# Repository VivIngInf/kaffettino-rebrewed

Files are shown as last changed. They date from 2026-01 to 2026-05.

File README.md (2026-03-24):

# ☕ Kaffettino Rebrewed (v2.0)

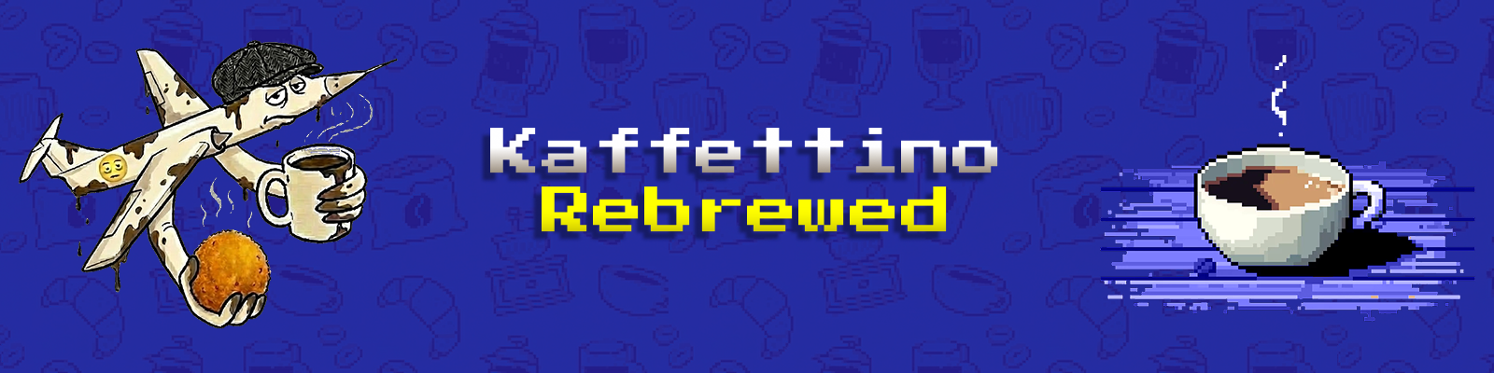
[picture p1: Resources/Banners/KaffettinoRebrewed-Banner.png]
Project's banner


> Sistema embedded NFC per la gestione automatizzata delle consumazioni, progettato per ambienti reali e scalabilità.




## ☀️ "Buongiornissimo... Arrikaffè!?!?!"

Kaffettino Rebrewed è la **nuova generazione del [progetto Kaffettino](https://github.com/VivIngInf/VivereKaffettino)**: non un semplice aggiornamento, ma una **riscrittura completa** pensata per essere più efficiente, robusta e pronta al futuro.

Se la prima versione era un prototipo brillante, questa è la sua evoluzione:
**hardware custom**, software **modulare** e una filosofia più **industriale**.

## ☕ Cos'è Kaffettino?

Vivere Kaffettino è una **suite** che permette agli utenti dell’Università di Palermo, appartenenti a Vivere Ingegneria, di **segnare le proprie consumazioni** (non solo di caffè) in modo semplice e veloce.

Il sistema è basato su un **ESP32 con lettore NFC**:

- L’utente avvicina la propria card
- Viene verificato il saldo
- Il costo del caffè viene scalato automaticamente

La ricarica viene poi gestita da un amministratore.

## 🤔 Cos’è cambiato con Rebrewed?

Kaffettino Rebrewed nasce come una **reingegnerizzazione completa** del [progetto originale](https://github.com/VivIngInf/VivereKaffettino), mantenendo lo spirito ma **rivoluzionando l’architettura**.

🔧 **Hardware & firmware**:

- PCB custom progettata ad hoc tramite KiCAD
- Firmware completamente riscritto e modularizzato
- Espandibilità grazie a morsettiere per device I2C e SPI
- Pensato per essere replicabile e manutenibile
- Aggiornamenti OTA

🖥️ **Backend**:

- Riscritto tutto il backend in TypeScript
- Integrato con il resto della suite Vivere
- Aggiunto Sito Web allo stack
- Continuazione del bot Telegram già presente nella versione 1

📡 **Connettività intelligente**:

- Riconnessione automatica
- Captive portal per configurazione WiFi
- Antenna esterna per maggiore copertura

🧯 **Gestione errori**:

- Sistema strutturato di gestione errori
- Debug più semplice
- Distinzione tra errori (bloccanti) e warning

## 🧱 Architettura

Kaffettino Rebrewed è composto da:

- ESP32 → legge NFC e comunica con backend
- Backend → gestisce utenti, saldo e logiche
- Web App → interfaccia admin ed utente per statistiche e gestione
- Bot Telegram → interazioni rapide

Tutti i **componenti** comunicano tramite **API REST**.

## 📚 Documentazione

La **documentazione** (utente e amministrativa) è disponibile nella **cartella Docs**.

## 📁 Struttura REPO

> WIP! 🚧

## 🖼️ Image Gallery

> WIP! 🚧

## ♥️ Credits

Realizzato **con amore**, debug e decisamente **troppa caffeina** dai ragazzi di Vivere Ingegneria Dev Hub

<table>
  <tr>
      <th>Daniele Susino</th>
      <th>Antonio Murabito</th>      
  </tr>
  <tr>
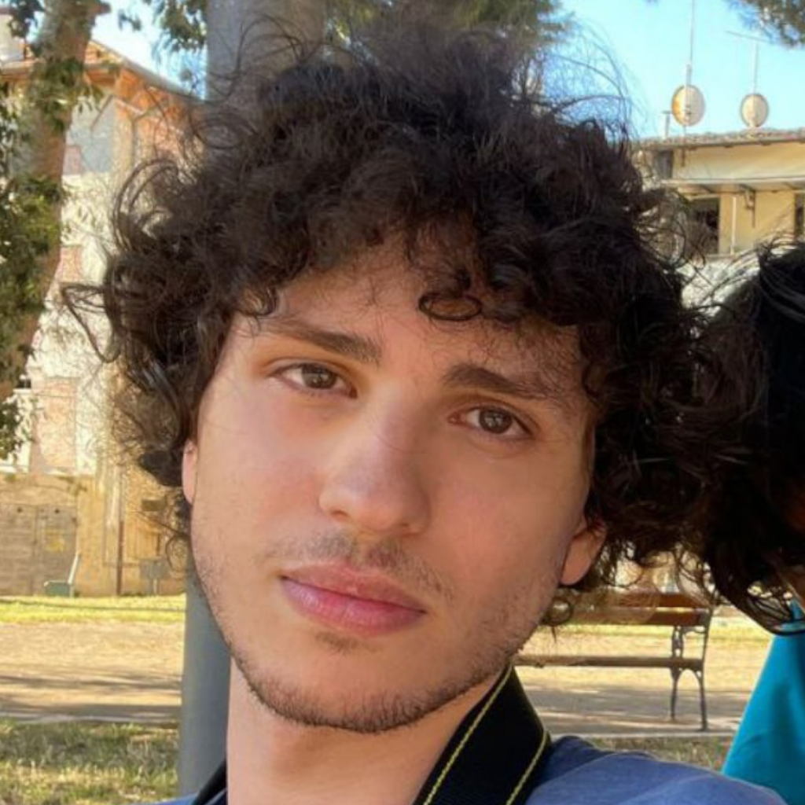
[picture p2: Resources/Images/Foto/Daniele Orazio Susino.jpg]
Daniele Orazio Susino
      <td></td>
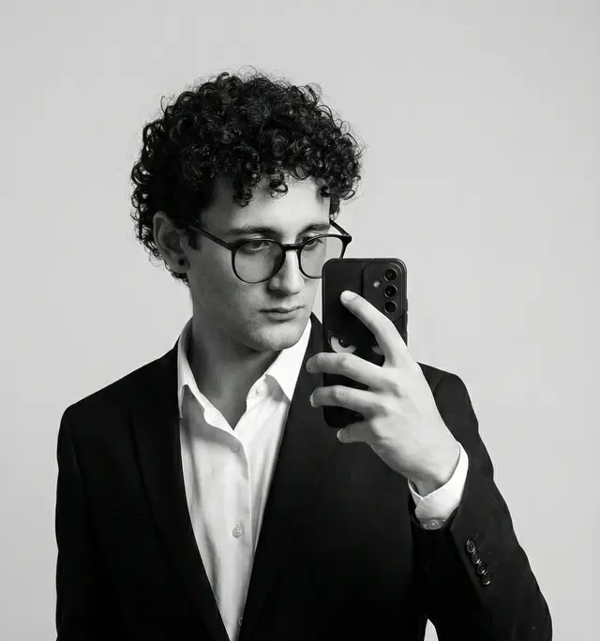
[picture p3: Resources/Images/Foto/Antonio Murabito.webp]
Antonio Murabito
      <td></td>
  </tr>
  <tr>
      <td>Embedded</td>
      <td>Full Stack</td>
  </tr>
  <tr>
      <td>
         <a href="https://www.instagram.com/_antonio.jar/">Instagram 📸</a><br>
         <a href="https://www.linkedin.com/in/susinodaniele/">LinkedIn 👔</a><br>         
         <a href="https://www.susino.dev">Sito 🌐</a>
      </td>
      <td>
         <a href="https://www.instagram.com/_antonio.jar/">Instagram 📸</a><br>
         <a href="https://www.linkedin.com/in/z3ros4n/">LinkedIn 👔</a><br>         
         <a href="https://www.msworks.it">Sito 🌐</a>
       </td>
  </tr>
</table>

---

Si ringrazia, per l'aiuto dato, Nicolas Bruno di [Objex Labs](https://objexlabs.com/)
<br>
Basato su: [Vivere Kaffettino](https://github.com/VivIngInf/VivereKaffettino)

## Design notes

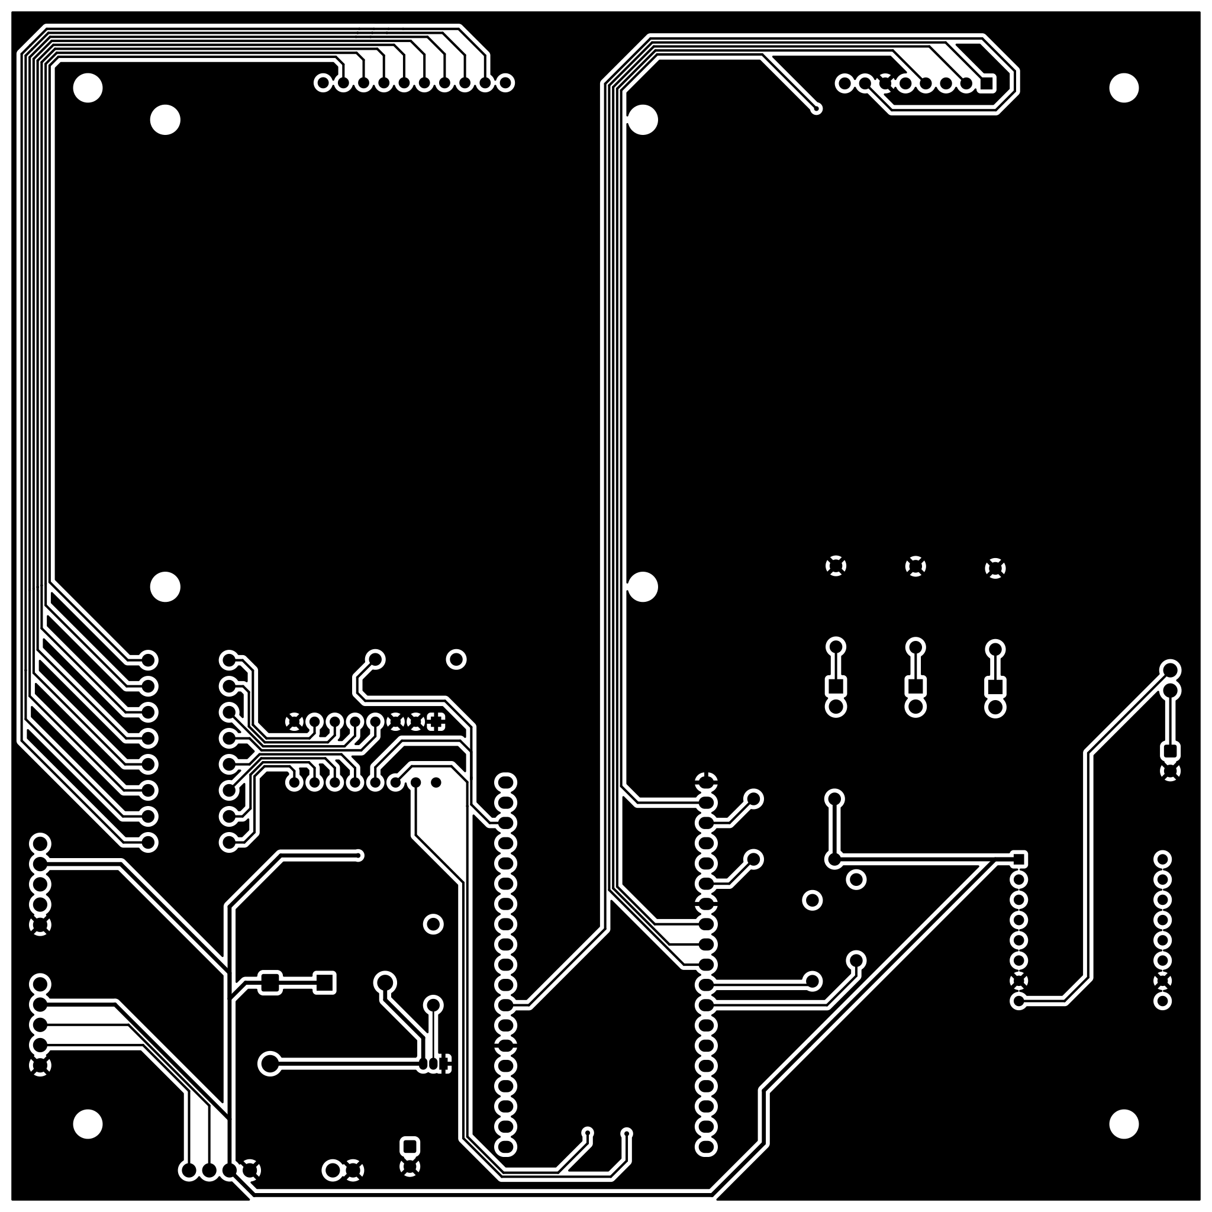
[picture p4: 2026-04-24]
Resources/Electronics/Kaffettino/Export/KaffettinoPCB/layers/PNGS/F_Cu.png

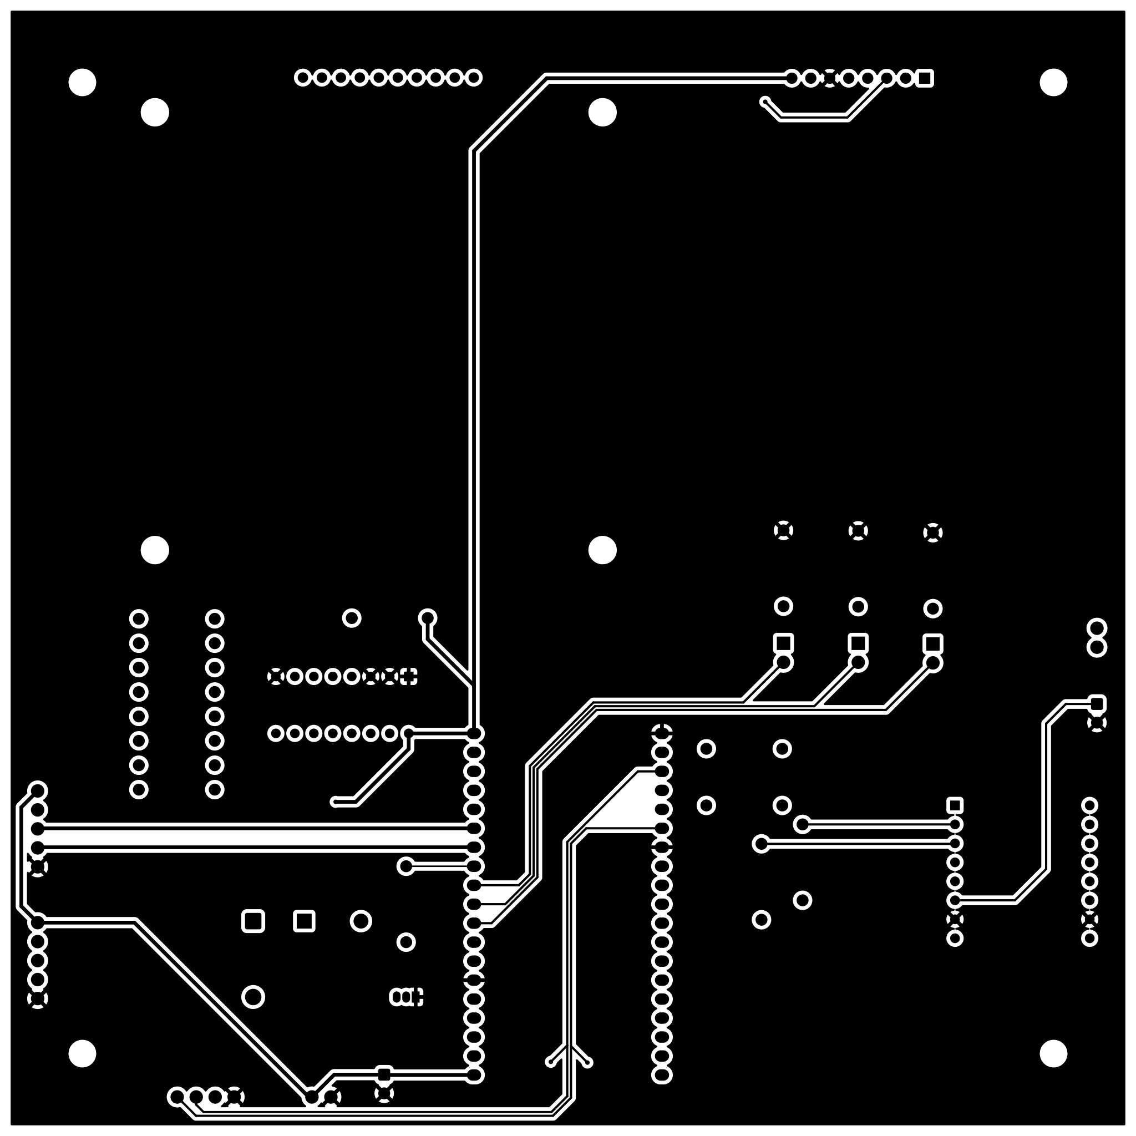
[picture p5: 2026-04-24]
Resources/Electronics/Kaffettino/Export/KaffettinoPCB/layers/PNGS/B_Cu.png

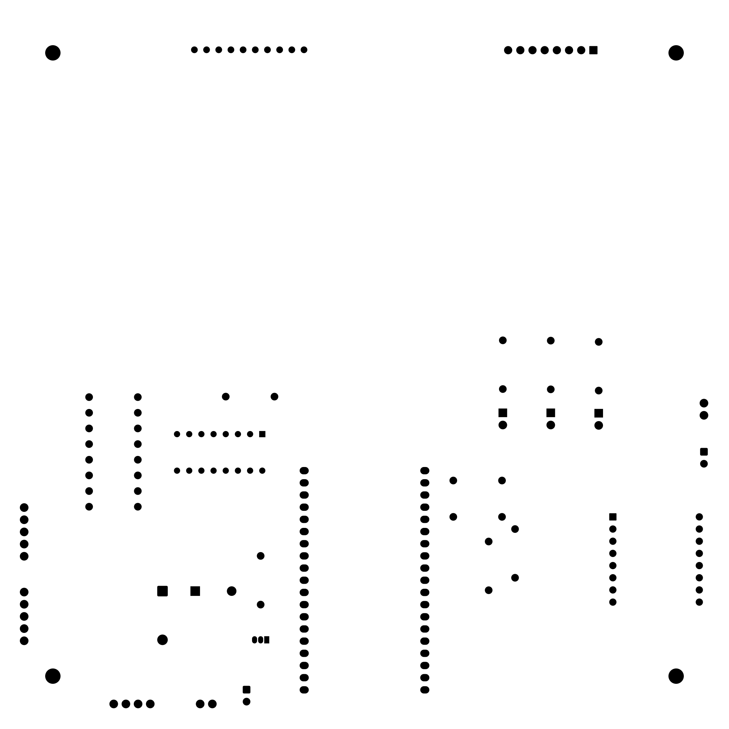
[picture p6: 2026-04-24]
Resources/Electronics/Kaffettino/Export/KaffettinoPCB/layers/PNGS/B_Mask.png

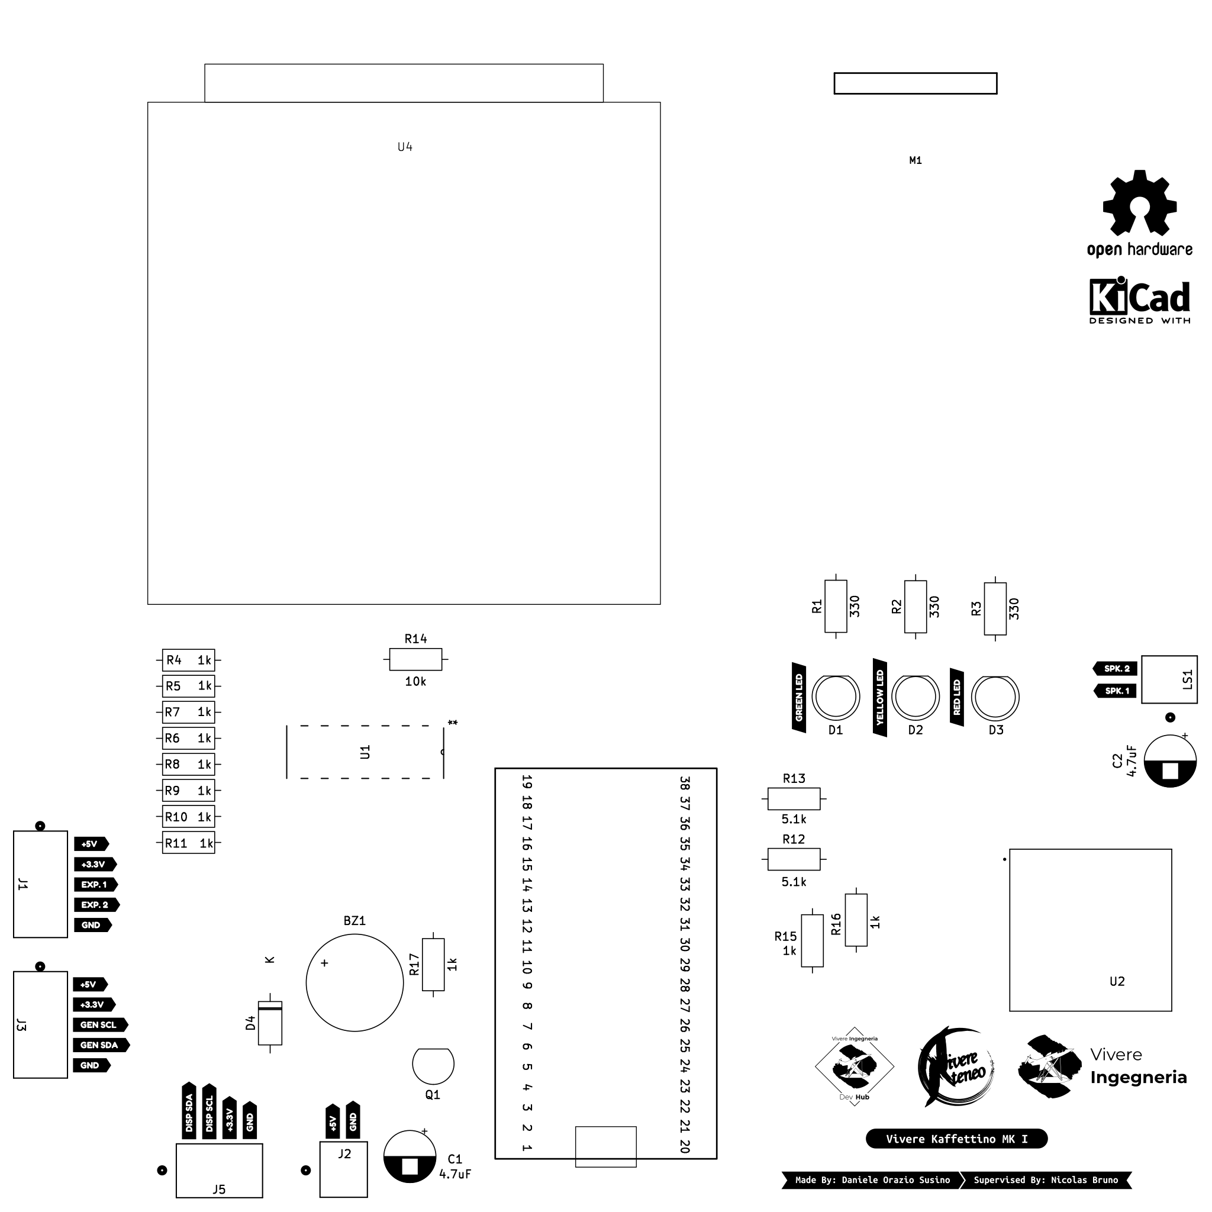
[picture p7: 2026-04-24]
Resources/Electronics/Kaffettino/Export/KaffettinoPCB/layers/PNGS/F_SilkS.png

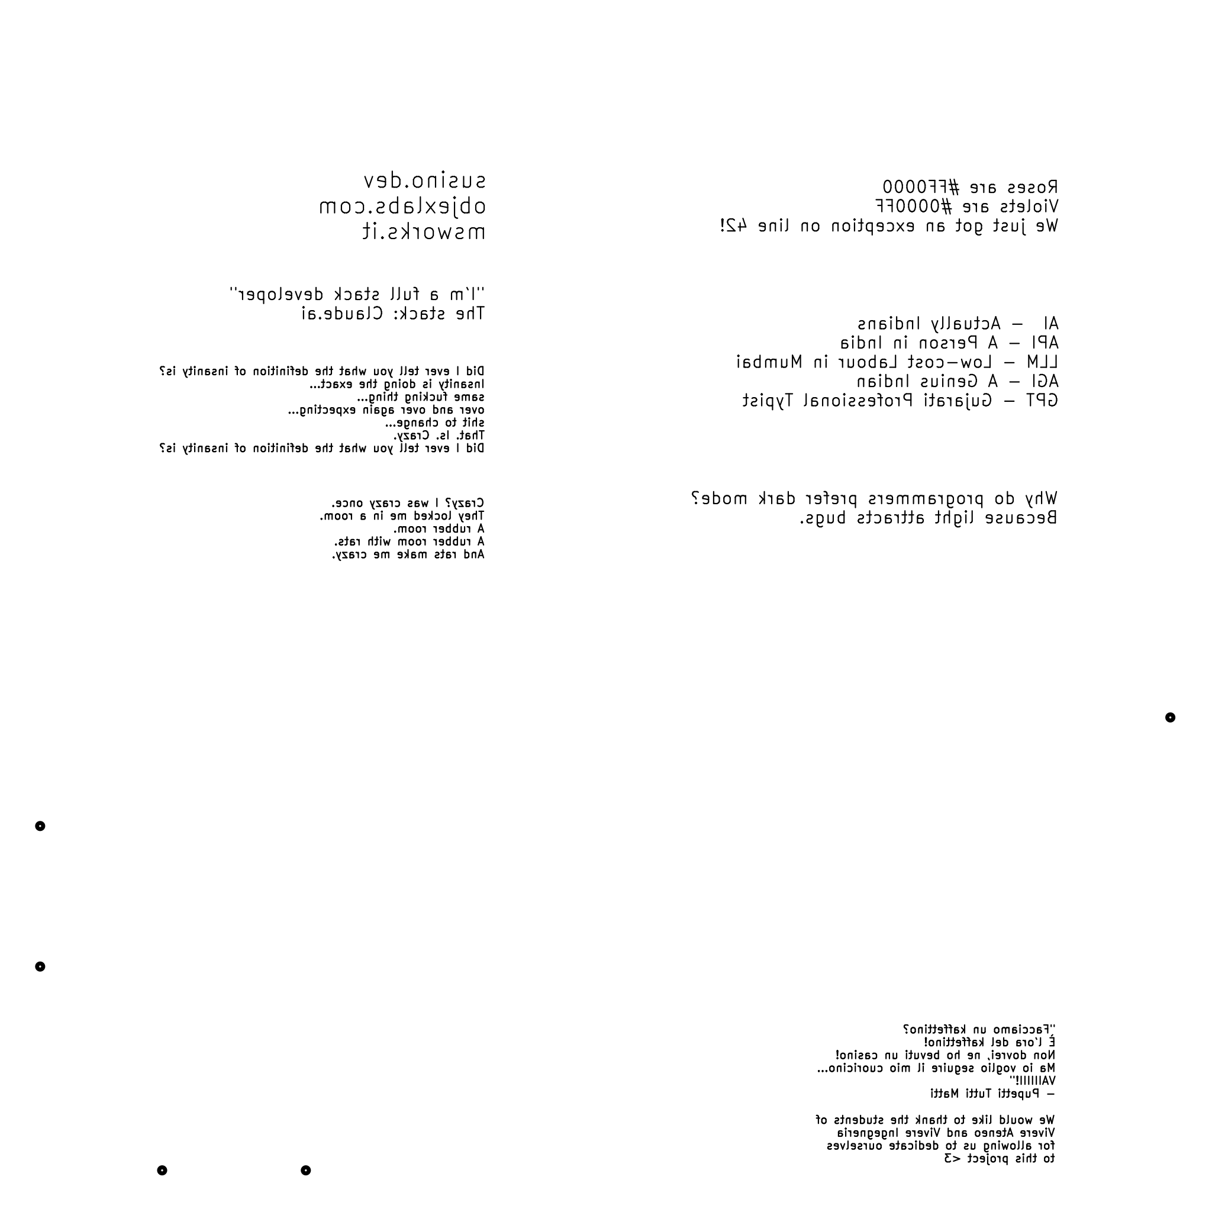
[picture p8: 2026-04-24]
Resources/Electronics/Kaffettino/Export/KaffettinoPCB/layers/PNGS/B_SilkS.png

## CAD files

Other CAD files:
Resources/3D Models/Keypad/Keypad.FCStd
Resources/Electronics/Kaffettino/Export/PCB.blend
Resources/Electronics/Kaffettino/Export/PCB_Ugly.blend

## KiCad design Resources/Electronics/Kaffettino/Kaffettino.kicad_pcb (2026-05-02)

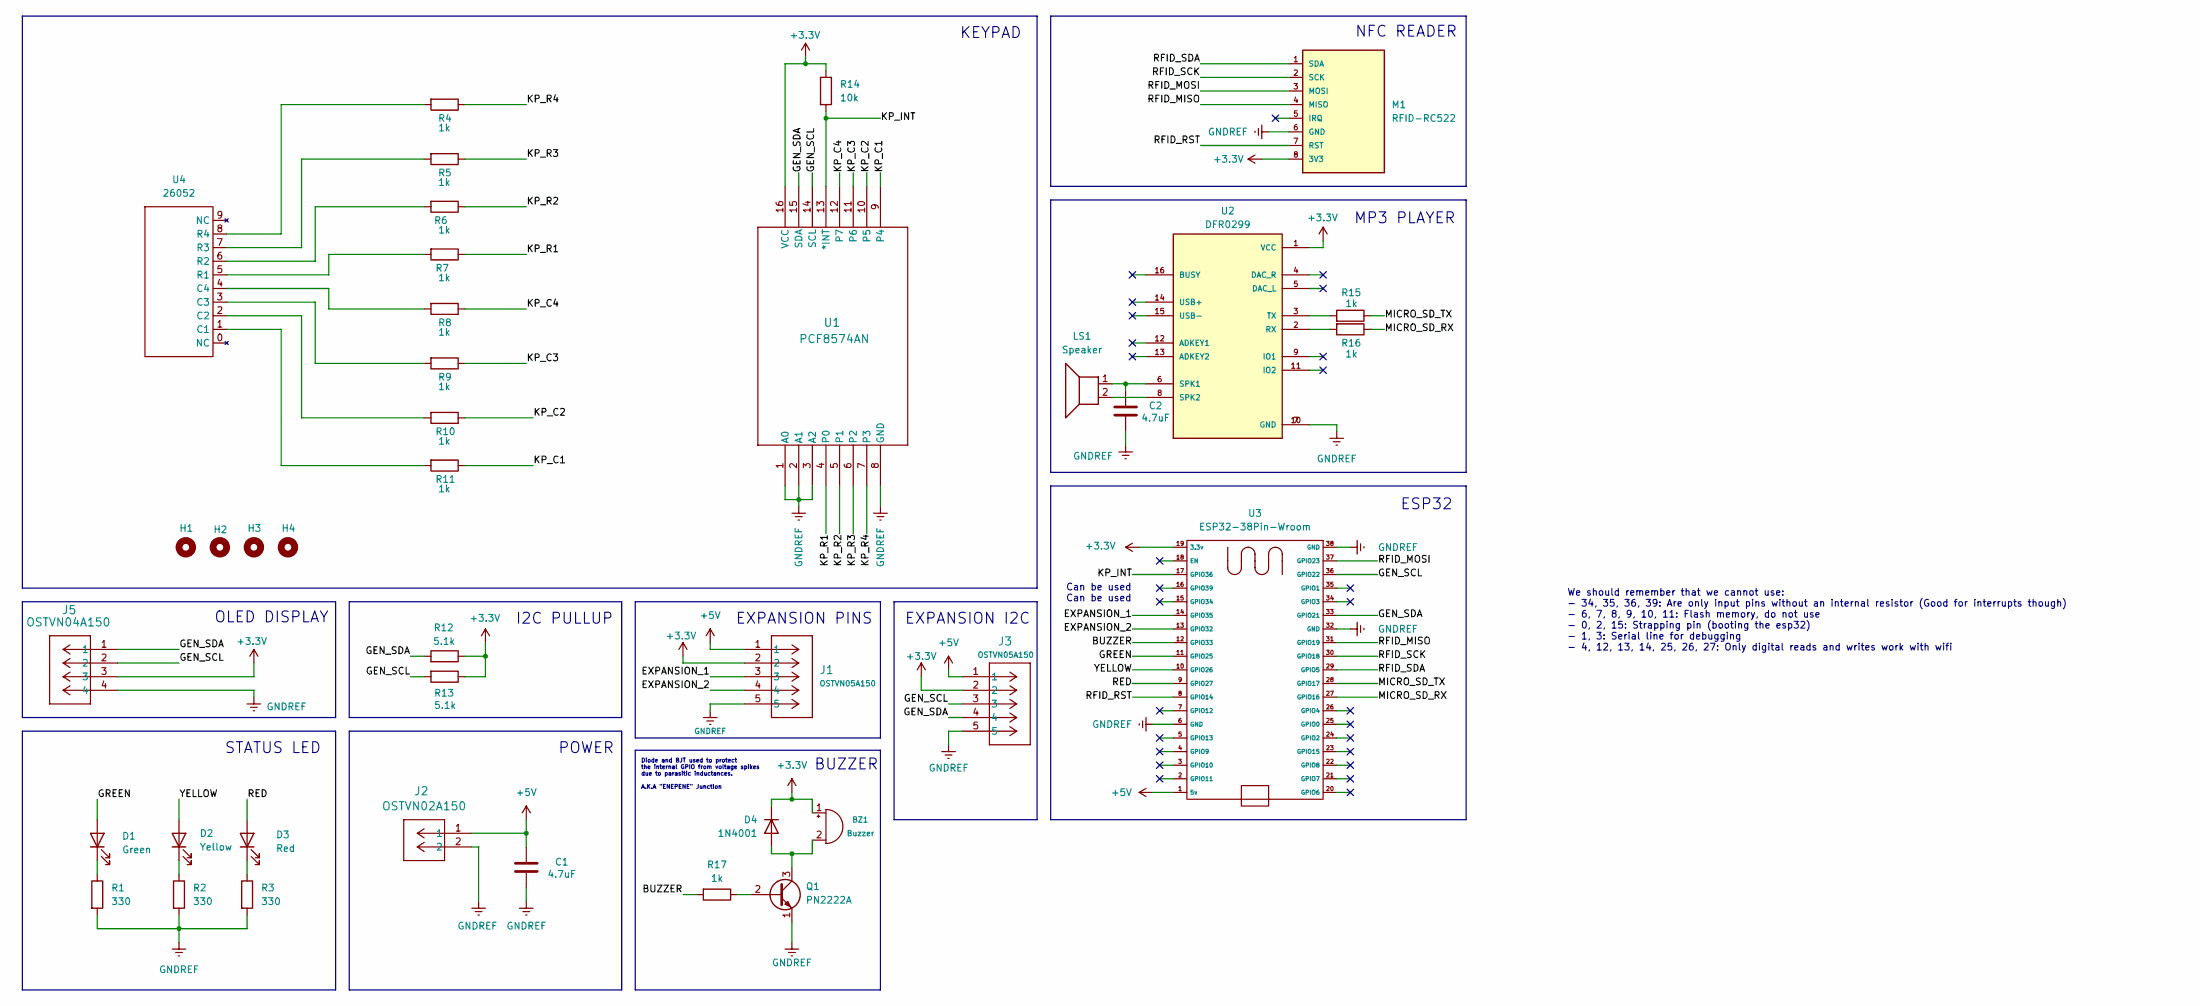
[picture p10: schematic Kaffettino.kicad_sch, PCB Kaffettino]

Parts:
BZ1: Buzzer; Buzzer_12x9.5RM7.6
C1, C2: 4.7uF; CP_Radial_D6.3mm_P2.50mm
D1: Green; LED_D5.0mm
D2: Yellow; LED_D5.0mm
D3: Red; LED_D5.0mm
D4: 1N4001; D_DO-41_SOD81_P10.16mm_Horizontal
H1, H2, H3, H4: MountingHole; MountingHole_3.2mm_M3
J1, J3: OSTVN05A150; CONN5_516x256_OST
J2: OSTVN02A150; CONN_OSTVN02A150_OST
J5: OSTVN04A150; CONN_OSTVN04A150_OST
LS1: Speaker; CONN_OSTVN02A150_OST
M1: RFID-RC522; MPN RFID-RC522
Q1: PN2222A; TO-92_Inline
R1, R2, R3: 330; R_Axial_DIN0207_L6.3mm_D2.5mm_P10.16mm_Horizontal
R4, R5, R6, R7, R8, R9, R10, R11, R15, R16, R17: 1k; R_Axial_DIN0207_L6.3mm_D2.5mm_P10.16mm_Horizontal
R12, R13: 5.1k; R_Axial_DIN0207_L6.3mm_D2.5mm_P10.16mm_Horizontal
R14: 10k; R_Axial_DIN0207_L6.3mm_D2.5mm_P10.16mm_Horizontal
U1: PCF8574AN; N16
U2: DFR0299; MODULE_DFR0299
U3: ESP32-38Pin-Wroom; ESP32_38pin
U4: 26052; 26052 matrix keypad 4x4

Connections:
+3.3V: BZ1.1 (+), D4.1 (K), J1.2, J3.2, J5.3, M1.8 (3V3), R12.1, R13.1, R14.1, U1.16 (VCC), U2.1 (VCC), U3.19 (3.3v)
+5V: C1.1, J1.1, J2.1, J3.1, U3.1 (5v)
/BUZZER: R17.2, U3.12 (GPIO33)
/EXPANSION_1: J1.3, U3.14 (GPIO35)
/EXPANSION_2: J1.4, U3.13 (GPIO32)
/GEN_SCL: J3.3, J5.2, R13.2, U1.14 (SCL), U3.36 (GPIO22)
/GEN_SDA: J3.4, J5.1, R12.2, U1.15 (SDA), U3.33 (GPIO21)
/GREEN: D1.2 (A), U3.11 (GPIO25)
/KP_C1: R11.1, U1.9 (P4)
/KP_C2: R10.1, U1.10 (P5)
/KP_C3: R9.1, U1.11 (P6)
/KP_C4: R8.1, U1.12 (P7)
/KP_INT: R14.2, U1.13 (*INT), U3.17 (GPIO36)
/KP_R1: R7.1, U1.4 (P0)
/KP_R2: R6.1, U1.5 (P1)
/KP_R3: R5.1, U1.6 (P2)
/KP_R4: R4.1, U1.7 (P3)
/MICRO_SD_RX: R16.1, U3.27 (GPIO16)
/MICRO_SD_TX: R15.1, U3.28 (GPIO17)
/RED: D3.2 (A), U3.9 (GPIO27)
/RFID_MISO: M1.4 (MISO), U3.31 (GPIO19)
/RFID_MOSI: M1.3 (MOSI), U3.37 (GPIO23)
/RFID_RST: M1.7 (RST), U3.8 (GPIO14)
/RFID_SCK: M1.2 (SCK), U3.30 (GPIO18)
/RFID_SDA: M1.1 (SDA), U3.29 (GPIO5)
/YELLOW: D2.2 (A), U3.10 (GPIO26)
GNDREF: C1.2, C2.2, J1.5, J2.2, J3.5, J5.4, M1.6 (GND), Q1.1 (E), R1.2, R2.2, R3.2, U1.1 (A0), U1.2 (A1), U1.3 (A2), U1.8 (GND), U2.7 (GND), U2.10 (GND), U3.6 (GND), U3.32 (GND), U3.38 (GND)
unnamed: BZ1.2 (-), D4.2 (A), Q1.3 (C)
unnamed: D1.1 (K), R1.1
unnamed: D2.1 (K), R2.1
unnamed: D3.1 (K), R3.1
unnamed: Q1.2 (B), R17.1
unnamed: R16.2, U2.2 (RX)
unnamed: C2.1, LS1.1, U2.6 (SPK1)
unnamed: LS1.2, U2.8 (SPK2)
unnamed: R15.2, U2.3 (TX)
unnamed: R11.2, U4.1 (C1)
unnamed: R10.2, U4.2 (C2)
unnamed: R9.2, U4.3 (C3)
unnamed: R8.2, U4.4 (C4)
unnamed: R7.2, U4.5 (R1)
unnamed: R6.2, U4.6 (R2)
unnamed: R5.2, U4.7 (R3)
unnamed: R4.2, U4.8 (R4)

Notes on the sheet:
Can be used
EXPANSION PINS
KEYPAD
EXPANSION I2C
BUZZER
ESP32
I2C PULLUP
STATUS LED
NFC READER
Diode and BJT used to protect the internal GPIO from voltage spikes due to parasitic inductances. A.K.A "ENEPENE" Junction
POWER
We should remember that we cannot use: - 34, 35, 36, 39: Are only input pins without an internal resistor (Good for interrupts though) - 6, 7, 8, 9, 10, 11: Flash memory, do not use - 0, 2, 15: Strapping pin (booting the esp32) - 1, 3: Serial line for debugging - 4, 12, 13, 14, 25, 26, 27: Only dig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
OLED DISPLAY
MP3 PLAYER

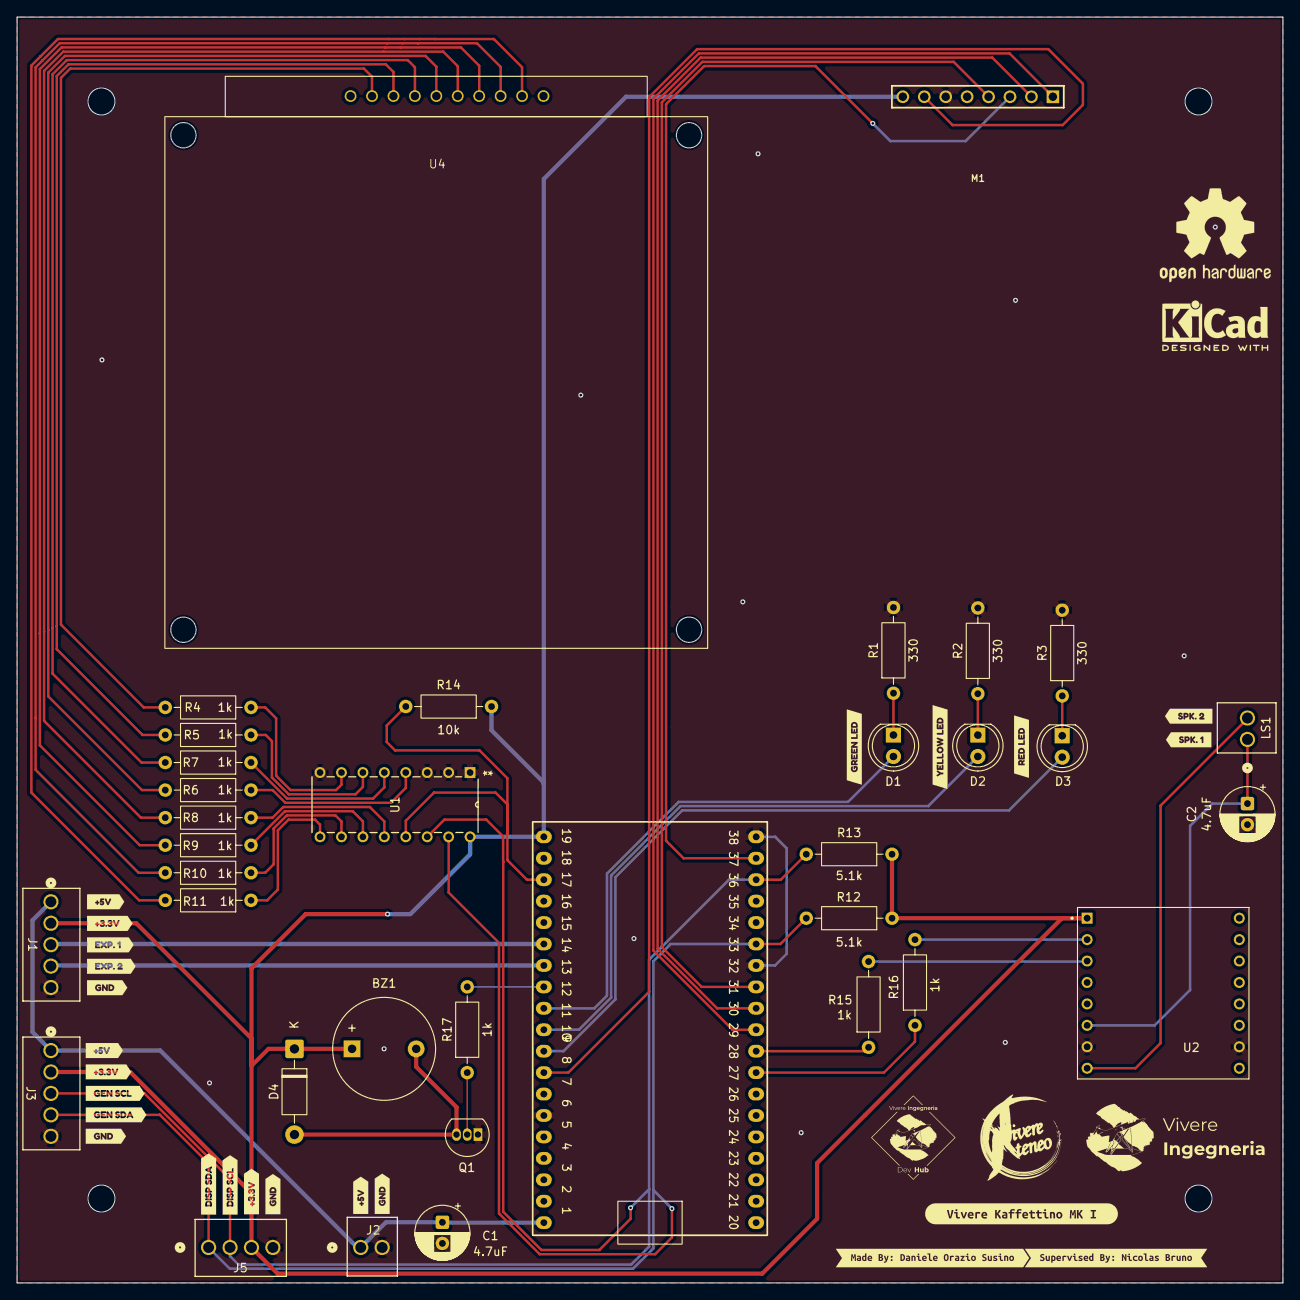
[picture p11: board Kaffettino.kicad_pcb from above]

Board: 2 copper layers, 150.0 x 150.0 mm, 63 parts (0 on the bottom side), 44 nets.

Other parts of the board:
kibuzzard-69A1A9EC: G***; kibuzzard-69A1A9EC
kibuzzard-69A1A9F8: G***; kibuzzard-69A1A9F8
kibuzzard-69A1A68F: G***; kibuzzard-69A1A68F
kibuzzard-69A1A69C: G***; kibuzzard-69A1A69C
kibuzzard-69A1A695: G***; kibuzzard-69A1A695
kibuzzard-69A1AA1D: G***; kibuzzard-69A1AA1D
kibuzzard-69A1AA2F: G***; kibuzzard-69A1AA2F
kibuzzard-69A1AA21: G***; kibuzzard-69A1AA21
kibuzzard-69A1AA26: G***; kibuzzard-69A1AA26
kibuzzard-69A1AA29: G***; kibuzzard-69A1AA29
kibuzzard-69A1AA32: G***; kibuzzard-69A1AA32
kibuzzard-69A1AB1B: G***; kibuzzard-69A1AB1B
kibuzzard-69A1AB21: G***; kibuzzard-69A1AB21
kibuzzard-69A1ABEC: G***; kibuzzard-69A1ABEC
kibuzzard-69A1AC2A: G***; kibuzzard-69A1AC2A
kibuzzard-69A1AC24: G***; kibuzzard-69A1AC24
kibuzzard-69A1B1F4: G***; kibuzzard-69A1B1F4
kibuzzard-69A1B1FA: G***; kibuzzard-69A1B1FA
kibuzzard-69A1B2CD, kibuzzard-69A1B2CD#2: G***; kibuzzard-69A1B2CD
kibuzzard-69A86FC7: G***; kibuzzard-69A86FC7
kibuzzard-69A188C8: G***; kibuzzard-69A188C8
kibuzzard-69A188E1: G***; kibuzzard-69A188E1
kibuzzard-69A188E6: G***; kibuzzard-69A188E6

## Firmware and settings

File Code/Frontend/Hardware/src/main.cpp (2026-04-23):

/* ----- Basic libs ----- */

#include <Arduino.h>

/* ----- Custom libs ----- */

#include "config.h"
#include "configWebServer.h"
#include "connectivity.h"
#include "nfcReader.h"
#include "display.h"
#include "mp3player.h"
#include "statusIndicator.h"
#include "buzzer.h"
#include "keypad.h"
#include "errorHandler.h"
#include "utility.h"
#include "logger.h"
#include "menu.h"
#include "keyEvents.h"

/* ----- Functions ----- */

void setup() 
{
    // Start serial comunication
    Serial.begin(115200);        

    if(!Serial)
        setError(ERR_SERIAL);

    #ifdef DEBUG_BUILD
        logInit(true, true, true);
    #else
        logInit(true, true);
    #endif

    // Start wire for I2C connection
    Wire.begin(GEN_SDA, GEN_SCL);
    
    #ifdef DEBUG_BUILD
        initBuzzer(false);
    #else
        initBuzzer(true);
    #endif

    initLEDs();
    changeLEDStatus(LED_WAIT);
    startBlinking();

    // Scan I2C network, outputs avaiable devices, mostly for debugging, expected 0x20 (keyboard), 0x3C (display) and ??? (Mp3)
    if(!hasError(ERR_SERIAL))
        scanI2CBus();

    // Setup the display first so we can communicate errors effectively
    if(!setupDisplay())
        setError(ERR_DISPLAY);   

    // Set the ESP as both a gateway and a client
    WiFi.mode(WIFI_AP_STA);

    // Load the WiFi credentials and general configs stored in memory
    initConfigs();

    // Start a web server to eventually change the WiFi network and credentials
    if(!startWebServer())
		setError(ERR_NETWORK);

    // Starts the NFC scanner, checks if version is valid, if it's not, an error occured
    if(!initNFCScanner())
        setError(ERR_NFC);

    initKeyEventBus();

    // Starts the keypad using the PCF8574-keypad lib, checks if correctly connected to I2C
    if(!initKeypad())
        setError(ERR_KEYPAD);

    // Starts the DFRobotMini MP3 player, checks if correctly connected to I2C
    if (!initMP3Player())
        setWarning(WARN_MP3);

    // Handles errors and warnings. Warnings are non blocking, meaning the ESP can proceed after showing them. Errors are blocking and the ESP will be restarted.
    handleErrors();

    initMenu();

    // If no error was found, play a joyful sound and start connecting
    bootSound();    
    startConnecting();
}

void loop() 
{    
    unsigned long now = millis();

    handleDNS(); // Processes DNS requests for the captive portal    
    
    handleBlink(now); // Handles the blink of the LEDs

    handleConnection(now); // Handles Wifi connection and errors

    // If the device isn't connected, it shouldn't proceed deeper in the code
    if(!isConnected())
        return;
        
    displayMainMenu();

    handleScanner(now);
    
    handleKeypad();
}

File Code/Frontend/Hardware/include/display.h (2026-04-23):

#pragma once

#include <U8g2lib.h>
#include <Wire.h>
#include <SPIFFS.h>
#include <errorHandler.h>

extern U8G2_SSD1309_128X64_NONAME2_F_SW_I2C display;

const int GEN_SCL = 22;
const int GEN_SDA = 21;

extern bool setupDisplay();

#define LCDWidth                        display.getDisplayWidth()
#define ALIGN_CENTER(t)                 ((LCDWidth - (display.getUTF8Width(t))) / 2) - HORIZONTAL_OFFSET
#define ALIGN_RIGHT(t)                  (LCDWidth -  display.getUTF8Width(t)) - HORIZONTAL_OFFSET
#define ALIGN_LEFT                      0
#define VERTICAL_OFFSET                 5
#define HORIZONTAL_OFFSET               1
#define VERTICAL_CENTER                 ((display.getDisplayHeight() / 2) + VERTICAL_OFFSET)

/* MESSAGES */

extern void displayConnecting(unsigned long now);
extern void displayConnected();
extern void displayConnectionError();
extern void displayErrorsAndWarning();
extern void displayWiFiNotFound();
extern void displayWrongPassword();
extern void displayConfigError();
extern void displayMainMenu();

extern void drawErrorDot(int x, int y, ERROR_LABELS error);
extern void drawWarningDot(int x, int y, WARNING_LABELS warning);

const uint8_t displayI2CAddress = 0x3C;

/* IMAGES */

static const unsigned char coffyNormale[] PROGMEM = {
  0x00,0xFC,0xFF,0xFF,0xFF,0xFF,0x3F,0x00,
  0x00,0xFC,0xFF,0xFF,0xFF,0xFF,0x3F,0x00,
  0x00,0x03,0x00,0x00,0x00,0x00,0xC0,0x00,
  0x00,0x03,0x00,0x00,0x00,0x00,0xC0,0x00,
  0xC0,0xFF,0xFF,0xFF,0xFF,0xFF,0xFF,0x03,
  0xC0,0xFF,0xFF,0xFF,0xFF,0xFF,0xFF,0x03,
  0x30,0x00,0x00,0x00,0x00,0x00,0x00,0x0C,
  0x30,0x00,0x00,0x00,0x00,0x00,0x00,0x0C,
  0x30,0x00,0x00,0x00,0x00,0x00,0x00,0x0C,
  0x30,0x00,0x00,0x00,0x00,0x00,0x00,0x0C,
  0xC0,0xFF,0xFF,0xFF,0xFF,0xFF,0xFF,0x03,
  0xC0,0xFF,0xFF,0xFF,0xFF,0xFF,0xFF,0x03,
  0xC0,0x00,0x00,0x00,0x00,0x00,0x00,0x03,
  0xC0,0x00,0x00,0x00,0x00,0x00,0x00,0x03,
  0xC0,0x00,0x00,0x00,0x00,0x00,0x00,0x03,
  0xC0,0x00,0x00,0x00,0x00,0x00,0x00,0x03,
  0xC0,0xF0,0xFF,0x03,0xC0,0xFF,0x0F,0x03,
  0xC0,0xF0,0xFF,0x03,0xC0,0xFF,0x0F,0x03,
  0xC0,0x00,0x00,0x00,0x00,0x00,0x00,0x03,
  0xC0,0x00,0x00,0x00,0x00,0x00,0x00,0x03,
  0xC0,0xC0,0xFF,0x03,0xC0,0xFF,0x03,0x03,
  0xC0,0xC0,0xFF,0x03,0xC0,0xFF,0x03,0x03,
  0xC0,0xF0,0xF3,0x0F,0xF0,0xFC,0x0F,0x03,
  0xC0,0xF0,0xF3,0x0F,0xF0,0xFC,0x0F,0x03,
  0xC0,0x30,0xC3,0x0F,0xF0,0xF0,0x0C,0x03,
  0xC0,0x30,0xC3,0x0F,0xF0,0xF0,0x0C,0x03,
  0x00,0x03,0x03,0xC3,0xC0,0xC0,0xC0,0x00,
  0x00,0x03,0x03,0xC3,0xC0,0xC0,0xC0,0x00,
  0x00,0x03,0x03,0xC3,0xC0,0xC0,0xC0,0x00,
  0x00,0x03,0x03,0xC3,0xC0,0xC0,0xC0,0x00,
  0x00,0x03,0xFC,0xC0,0x00,0x3F,0xC0,0x00,
  0x00,0x03,0xFC,0xC0,0x00,0x3F,0xC0,0x00,
  0x00,0x03,0x00,0xC0,0x03,0x00,0xC0,0x00,
  0x00,0x03,0x00,0xC0,0x03,0x00,0xC0,0x00,
  0x00,0x03,0x00,0x00,0x00,0x00,0xC0,0x00,
  0x00,0x03,0x00,0x00,0x00,0x00,0xC0,0x00,
  0x00,0x03,0x00,0x03,0xC0,0x00,0xC0,0x00,
  0x00,0x03,0x00,0x03,0xC0,0x00,0xC0,0x00,
  0x00,0x03,0x00,0xFC,0x3F,0x00,0xC0,0x00,
  0x00,0x03,0x00,0xFC,0x3F,0x00,0xC0,0x00,
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
};

static const unsigned char coffyTriste[] PROGMEM = {
	0x00,0xFC,0xFF,0xFF,0xFF,0xFF,0x3F,0x00,
	0x00,0xFC,0xFF,0xFF,0xFF,0xFF,0x3F,0x00,
	0x00,0x03,0x00,0x00,0x00,0x00,0xC0,0x00,
	0x00,0x03,0x00,0x00,0x00,0x00,0xC0,0x00,
	0xC0,0xFF,0xFF,0xFF,0xFF,0xFF,0xFF,0x03,
	0xC0,0xFF,0xFF,0xFF,0xFF,0xFF,0xFF,0x03,
	0x30,0x00,0x00,0x00,0x00,0x00,0x00,0x0C,
	0x30,0x00,0x00,0x00,0x00,0x00,0x00,0x0C,
	0x30,0x00,0x00,0x00,0x00,0x00,0x00,0x0C,
	0x30,0x00,0x00,0x00,0x00,0x00,0x00,0x0C,
	0xC0,0xFF,0xFF,0xFF,0xFF,0xFF,0xFF,0x03,
	0xC0,0xFF,0xFF,0xFF,0xFF,0xFF,0xFF,0x03,
	0xC0,0x00,0x00,0x00,0x00,0x00,0x00,0x03,
	0xC0,0x00,0x00,0x00,0x00,0x00,0x00,0x03,
	0xC0,0x00,0xFC,0x03,0xC0,0x3F,0x00,0x03,
	0xC0,0x00,0xFC,0x03,0xC0,0x3F,0x00,0x03,
	0xC0,0xF0,0x03,0x00,0x00,0xC0,0x0F,0x03,
	0xC0,0xF0,0x03,0x00,0x00,0xC0,0x0F,0x03,
	0xC0,0x00,0x00,0x00,0x00,0x00,0x00,0x03,
	0xC0,0x00,0x00,0x00,0x00,0x00,0x00,0x03,
	0xC0,0xC0,0xFF,0x03,0xC0,0xFF,0x03,0x03,
	0xC0,0xC0,0xFF,0x03,0xC0,0xFF,0x03,0x03,
	0xC0,0xF0,0xF3,0x0F,0xF0,0xFC,0x0F,0x03,
	0xC0,0xF0,0xF3,0x0F,0xF0,0xFC,0x0F,0x03,
	0xC0,0x30,0xC3,0x0F,0xF0,0xF0,0x0C,0x03,
	0xC0,0x30,0xC3,0x0F,0xF0,0xF0,0x0C,0x03,
	0x00,0x03,0x03,0xC3,0xC0,0xC0,0xC0,0x00,
	0x00,0x03,0x03,0xC3,0xC0,0xC0,0xC0,0x00,
	0x00,0x03,0x03,0xC3,0xC0,0xC0,0xC0,0x00,
	0x00,0x03,0x03,0xC3,0xC0,0xC0,0xC0,0x00,
	0x00,0x03,0xFC,0xC0,0x00,0x3F,0xC0,0x00,
	0x00,0x03,0xFC,0xC0,0x00,0x3F,0xC0,0x00,
	0x00,0x03,0x00,0xC0,0x03,0x00,0xC0,0x00,
	0x00,0x03,0x00,0xC0,0x03,0x00,0xC0,0x00,
	0x00,0x03,0x00,0x00,0x00,0x00,0xC0,0x00,
	0x00,0x03,0x00,0x00,0x00,0x00,0xC0,0x00,
	0x00,0x03,0x00,0xFC,0x3F,0x00,0xC0,0x00,
	0x00,0x03,0x00,0xFC,0x3F,0x00,0xC0,0x00,
	0x00,0x03,0x00,0x03,0xC0,0x00,0xC0,0x00,
	0x00,0x03,0x00,0x03,0xC0,0x00,0xC0,0x00,
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
};

static const unsigned char coffyMorto[] PROGMEM = {
	0xE0,0xFF,0xFF,0x07,
	0x10,0x00,0x00,0x08,
	0xF8,0xFF,0xFF,0x1F,
	0x04,0x00,0x00,0x20,
	0x04,0x00,0x00,0x20,
	0xF8,0xFF,0xFF,0x1F,
	0x08,0x00,0x00,0x10,
	0x08,0x00,0x00,0x10,
	0xC8,0x1F,0xF8,0x13,
	0x08,0x00,0x00,0x10,
	0x48,0x10,0x08,0x12,
	0x88,0x08,0x10,0x11,
	0x08,0x05,0xA0,0x10,
	0x10,0x82,0x40,0x08,
	0x10,0x85,0xA0,0x08,
	0x90,0x88,0x10,0x09,
	0x50,0x90,0x09,0x0A,
	0x10,0x00,0x00,0x08,
	0x10,0xFE,0x7F,0x08,
	0x10,0x00,0x48,0x08,
	0x20,0x00,0x48,0x04,
	0x20,0x00,0x48,0x04,
	0x20,0x00,0x30,0x04,
	0x20,0x00,0x00,0x04,
	0xE0,0xFF,0xFF,0x07,
	0x40,0x20,0x04,0x02,
	0x40,0x25,0x44,0x02,
	0x40,0xC3,0x53,0x02,
	0x40,0x45,0xFA,0x02,
	0x40,0x40,0x02,0x02,
	0x40,0x40,0x02,0x02,
	0x80,0xFF,0xFF,0x01
};
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

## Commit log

2025-11-16 Corrected some footprints in the PCB schema
    [Kaffettino.kicad_pcb, Kaffettino.kicad_sch]
2025-11-18 Add wallet request feature and related endpoints
    Introduces the WalletRequest model and RequestStatus enum in the Prisma schema to support wallet creation requests. Adds new API endpoints for users to request wallet creation and for admins/treasure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
2025-11-20 Add wallet and top-up search with pagination support
    Introduces utility types for pagination and range search, and updates wallet routes to support filtered and paginated queries for wallets and top-ups. Implements corresponding handler methods to fetc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
2025-11-26 Add device API scaffolding and update wallet topup
    Introduces initial scaffolding for device-related API endpoints, including a request decorator and middleware. Also updates the wallet topup endpoint to require a description field in the request pay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
2025-11-27 ESP32 WebServer Initialization
2025-11-29 Embedded: Config html completed, connectivity lacks failback in case it randomly drops.
    [fallbackWebServer.cpp, main.cpp]
2025-12-02 Fixed a missplaced lable in electrical schema
    [Kaffettino.kicad_sch]
2025-12-03 NFC Reader interrupt
    [Kaffettino.kicad_sch]
2025-12-03 Add device handler utility and update device API
    Introduced a new device-handler utility for device operations. Updated the device API route and Prisma plugin to use the new utility. Added @prisma/adapter-pg and testing dependencies, and updated th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
2025-12-04 Refactor device registration and error handling
    Updated Prisma schema to make device fields optional and removed DeviceLog model. Enhanced device registration flow to check for verified devices and pending requests, and added new utility methods for device registration management. Error handling now supports localized messages loaded from JSON files. Added English message definitions.
2025-12-04 Add endpoint to accept device registration requests
    Introduces a PUT /device endpoint restricted to admins for accepting device registration requests. Updates error messages and improves parameter validation for device registration.
2025-12-07 Add device API key management and middleware
    Introduces device API key generation, validation, and authorization logic in device-handler. Adds device middleware for API key authentication, updates request/response structures in device routes, and extends FastifyRequest with deviceName. Also updates English messages for device errors.
2025-12-07 Update device registration flow and status handling
    Renamed RequestStatus enum value from SENT_TO_CLIENT to AWAITING_CLIENT and updated all related logic and references. Improved device registration endpoint to check for AWAITING_CLIENT status, added error messaging for missing accepted requests, and implemented completion of device requests. Changed access key regeneration endpoint to use PUT and refactored device-handler utilities for new status handling.
2025-12-09 Add card and aulette handlers, extend device API
    Introduced card and aulette handler utilities, middleware for card validation, and new device API endpoints for aulette, inventory, and wallets. Updated Fastify request types to include card information, added new error messages, and enhanced inventory handler with getInventories method. These changes support device-specific inventory and wallet queries, and improve error handling for card and aulette operations.
2025-12-11 Add product purchase endpoint and transaction handling
    Introduces a new /device/buy-product endpoint for purchasing products via devices, including birthday and custom discounts. Adds transaction-handler utility for registering transactions and updating wallet balances, extends the Transaction model with type and device relations, and updates related decorators, types, and error messages for improved device and card handling.
2025-12-12 Add card API routes and refactor imports to ESM
    Introduces new /card API endpoints for creating cards and updating card PINs, including validation and permission checks. Refactors all internal imports to use explicit ESM '.js' extensions and updates handler utilities for card and wallet management. Also adds a new error message for card PIN requirements and cleans up unused imports.
2025-12-14 Working mp3 player, oled screen and nfc scanner
    [Kaffettino.kicad_sch]
2025-12-14 Embedded: Added Buzzer and LED support
    [Kaffettino.kicad_sch]
2025-12-14 Add card block/unblock functionality and API endpoints
    Introduces a 'blocked' field to the Card model and adds logic to block or unblock cards via new API endpoints. Middleware and card handler are updated to enforce blocked status, returning an error if a blocked card is used. Also adds relevant messages and a new device route for wallet-auletta retrieval.
2025-12-20 Embedded: Completed integration of the sensors and boards. Now will start implementation
    [Kaffettino.kicad_sch]
2025-12-25 Add audit logging to API route handlers
    Introduced auditLog calls to card, device, inventory, user, and wallet route handlers to record key actions such as creation, updates, and transactions. This enhances traceability and accountability 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
2025-12-30 Switch kaffettino to Bun, update dependencies
    Replaced npm's package-lock.json with bun.lock for both the root and kaffettino directories, updated package.json dependencies, and adjusted .gitignore. Updated Prisma configuration and schema files to align with the new setup.
2026-01-07 Trying images on display and almost finished PCB design.
    [Kaffettino.kicad_pcb, Kaffettino.kicad_sch, Keypad.FCStd]
2026-01-07 Finished routing in PCB, waiting for approval
    [Kaffettino.kicad_pcb, Kaffettino.kicad_sch]
2026-01-08 Update CORS origin and validate device location param
    Changed default CORS origin to http://localhost:6969. Added validation for the 'location' query parameter in the device route, returning a 400 error if missing.
2026-01-08 Refactor device route and update env vars in config
    Removed mandatory 'location' param check from the device route and adjusted aulette handler to handle undefined locations. Also added new environment variables to ecosystem.config.js for improved con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
2026-01-10 Add UI components and update homepage layout
    Introduced new UI components (badge, button, card, drawer, input, separator, textarea, etc.) and a ServiceCard component for the homepage. Updated the homepage layout to showcase services with a new 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
2026-01-23 Embedded: Added critical error message
    [display.cpp, display.h, main.cpp]
2026-01-23 Embedded: Started error handleing
    [main.cpp]
2026-01-23 Embedded: handled all init errors, differentiated between warnings and errors
    [configWebServer.cpp, display.cpp, display.h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]
2026-01-24 Embedded: created a custom logging utility, migrated all logging to new framework
2026-02-04 Embedded: Improved connection script, added connection errors, started dynamic WiFi selection in HTML.
    [configWebServer.cpp, display.cpp, display.h]
2026-02-07 Add OpenAPI schemas to v1 API routes
    Add JSON schema (OpenAPI) objects to v1 route handlers to improve request/response validation and API documentation. Changes span device, inventory, ping, protected, user and wallet routes and include descriptions, tags, security, request body/query/header schemas and detailed responses (200/400/401/404/409/500 as appropriate). Also includes minor formatting/comma fixes and improved parameter validations. Files modified: device.ts, inventory.ts, ping.ts, protected.ts, user.ts, wallet.ts.
2026-02-08 Add Course model, update auth and frontend auth
    Add a Course model to Prisma and link it to User (courseId relation with SetNull on delete, unique name, timestamps). Expose courseId in the backend auth configuration. Add frontend auth pages and co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
2026-02-08 Support multiple CORS origins; enable signup
    Allow multiple origins in the backend CORS plugin (uses CLIENT_ORIGIN or http://localhost:6969 and adds http://localhost:3000) via an origin callback to permit local dev from Next.js. Update frontend sign-up flow to actually call authClient.signUp.email and log the response/error. Adjust auth-client baseURL to include the API prefix (/api/v1/) so frontend requests target the correct API path.
2026-02-09 Auth origins, session cookie fix, signup UI cleanup
    Backend: set auth baseURL to process.env.API_BASE_URL (fallback IP) and expand trustedOrigins to include local Next.js and backend addresses so requests and origin checks match the backend address. Frontend (kaffettino layout): forward the cookie header to authClient.getSession (renamed headers var to headersList), add short debug logs, and log the session; this ensures server-side session retrieval works. Frontend (sign-up): remove birthDate and course from the registration payload and comment out the related form fields/UI, simplifying the signup flow and matching the submitted data shape.
2026-02-09 Log cookies and disable secure cookies temporarily
    Print the full cookie header in the Kaffettino layout for debugging and temporarily disable secure cookies in the backend auth client. layout.tsx now logs cookieHeader value to aid troubleshooting; a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
2026-02-24 Embedded: fixed some footprints in the PCB design, started working on keyEvents.
    [Kaffettino-B_Cu.gbr, Kaffettino-B_Mask.gbr, Kaffettino-B_Paste.gbr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]
2026-02-27 Embedded: Finished developing PCB, fixed grb and drill files, added silkscreen.
    TODO: Check correctness of footprints and NPN Junction.
    [Kaffettino-B_Cu.gbr, Kaffettino-B_Mask.gbr, Kaffettino-B_Paste.gbr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]
2026-02-27 Embedded: Switched buzzer from 15 (strapping pin) to 33, reflected the changes in the PCB
    [Kaffettino-B_Cu.gbr, Kaffettino-B_Mask.gbr, Kaffettino-B_Paste.gbr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]
2026-02-27 Embedded: Incresed size of silkscreen
    [Kaffettino-B_Cu.gbr, Kaffettino-B_Mask.gbr, Kaffettino-B_Paste.gbr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]
2026-02-27 Embedded: Added 5V to expansion headers
    [Kaffettino.kicad_pcb, Kaffettino.kicad_sch]
2026-02-27 Embedded: Forgot to update gbr and drill files
    [Kaffettino-B_Cu.gbr, Kaffettino-B_Mask.gbr, Kaffettino-B_Paste.gbr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]
2026-03-04 Add device zod schemas and validate routes
    Introduce zod schemas for device payloads (deviceRegistrationSchema, deviceValidateId, deviceValidateName, deviceValidateNameAndId) and corresponding TypeScript types (IDeviceRegistrationSchema, IDeviceValidateId, IDeviceValidateName, IDeviceValidateNameAndId). Update device routes to import these schemas/types, replace manual property checks with schema.safeParse validations, adjust request body typings to use the new interfaces (making some fields optional where appropriate), and remove an unused deviceName parameter from an endpoint's OpenAPI schema. This centralizes validation and improves type safety for device-related endpoints.
2026-03-04 Fixed wrong PCB label 3.3 to 5V
    [Kaffettino-B_Cu.gbr, Kaffettino-B_Mask.gbr, Kaffettino-B_Paste.gbr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]
2026-03-15 Embedded: Fixed some text width so that JLCPCB's DRC won't whine about it
    [Kaffettino-B_Cu.gbr, Kaffettino-B_Mask.gbr, Kaffettino-B_Paste.gbr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]
2026-04-20 Debug Mode, Pragma everywhere, Checks on SPIFFS, removed magic numbers, fixed platformio.ini, added keypad support (thanks claude, will refactor)
    [configWebServer.cpp]
2026-04-23 Main Menu on PCB and full PCB models on Kicad, exported on blender
    [Kaffettino.kicad_pcb, PCB.blend]
2026-04-24 Export images PCB, created ugly PCB for Samuele (shitty PC)
    [PCB_Ugly.blend]
2026-05-02 Fix path issues with buzzer in PCB
    [Kaffettino.kicad_pcb]
